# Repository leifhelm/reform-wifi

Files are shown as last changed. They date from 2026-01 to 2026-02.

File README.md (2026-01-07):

# WiFi Adapter for MNT Reform

This module is **untested**.

This adapter uses the PCIe and USB interfaces of the RCORE module, like the Pocket Reform.

The schematic is largely from [pocket-reform-wifi](https://source.mnt.re/reform/pocket-reform/-/tree/2fd691b93a8a8b05e923d17600f8ea777f0ab824/pocket-reform-wifi).

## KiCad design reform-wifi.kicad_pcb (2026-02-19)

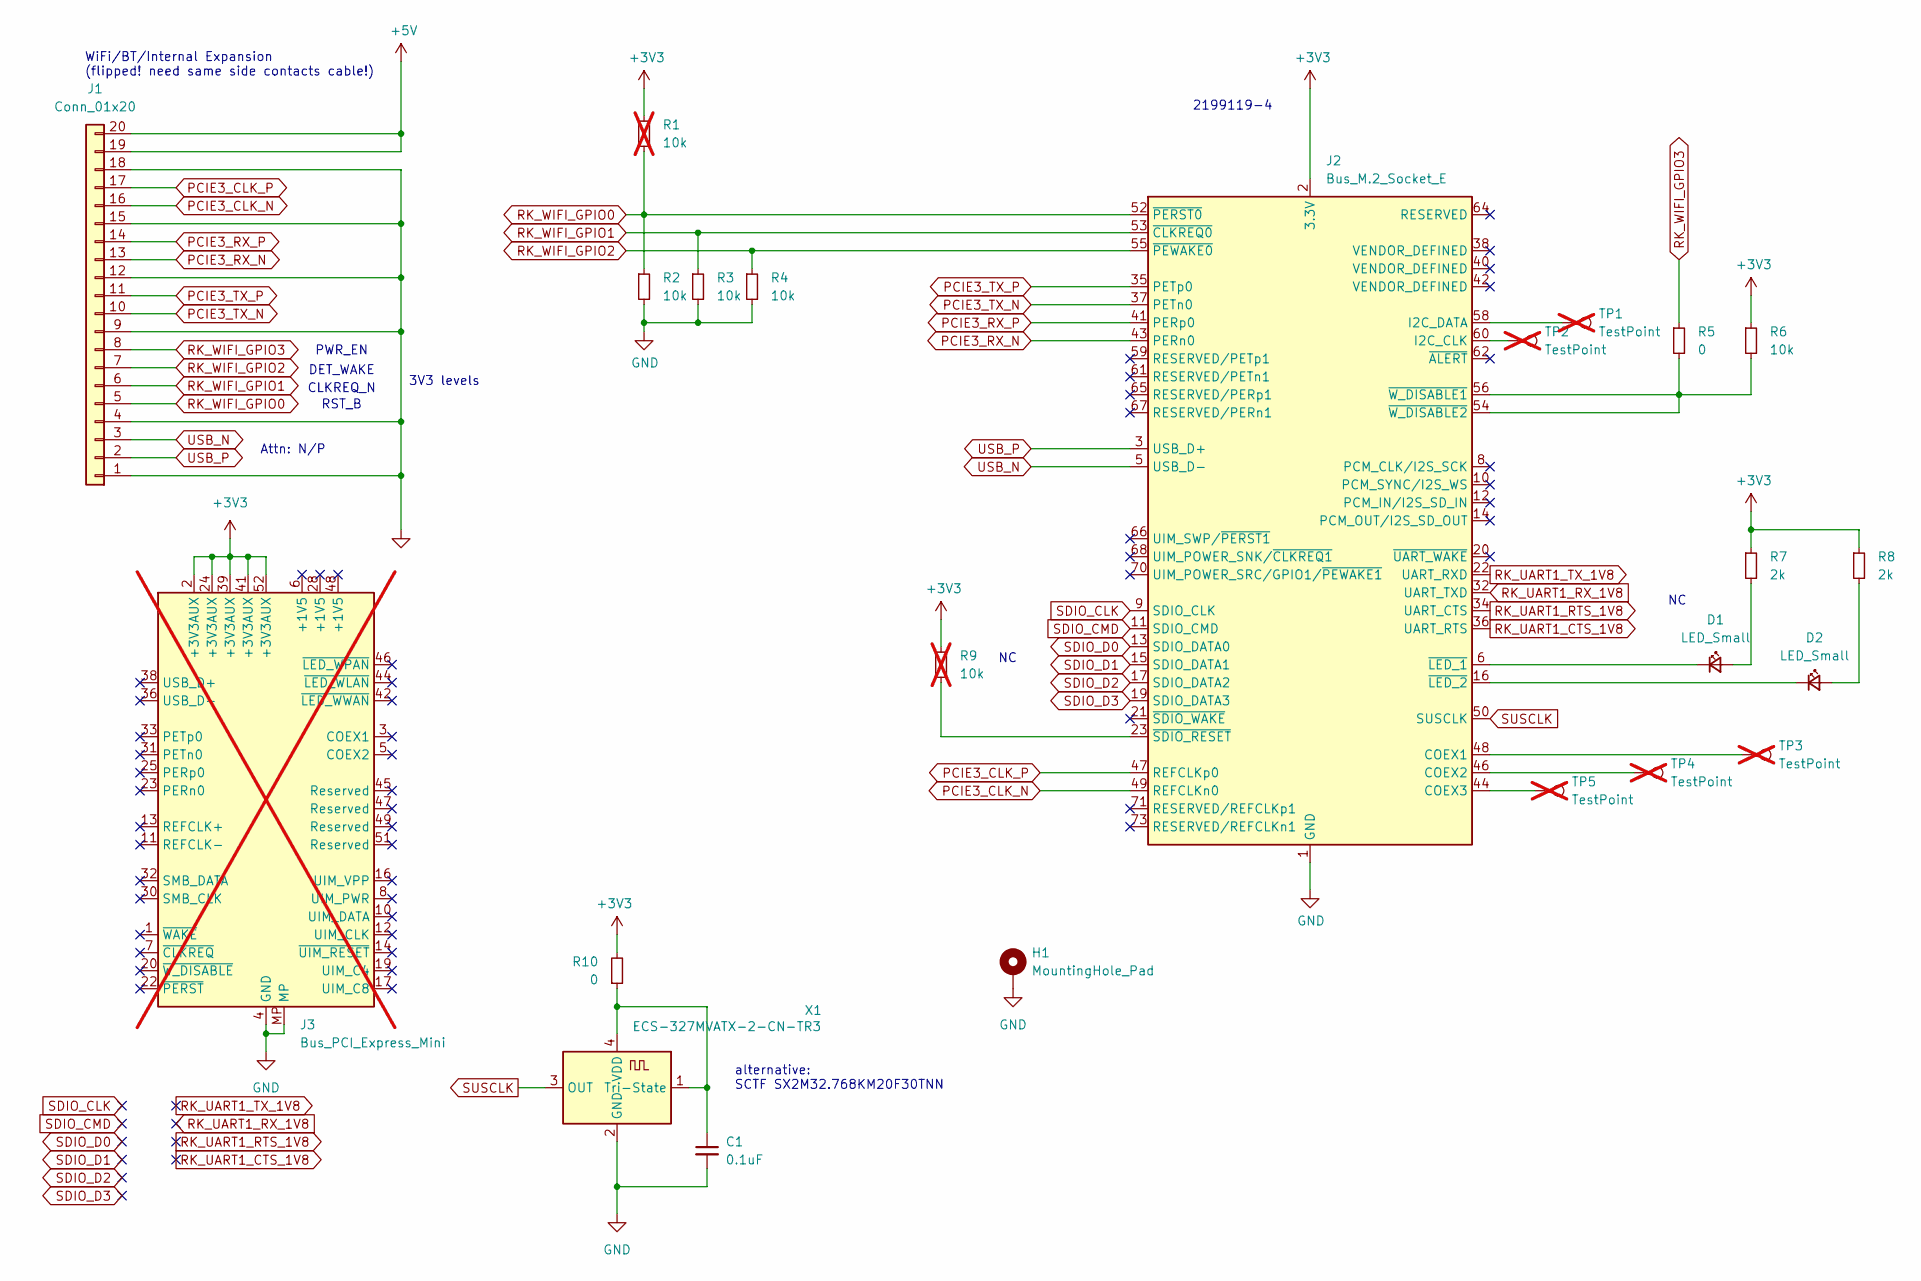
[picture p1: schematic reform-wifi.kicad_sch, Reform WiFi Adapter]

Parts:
C1: 0.1uF; C_0603_1608Metric; LCSC C77058
D1, D2: LED_Small; LED_0603_1608Metric; LCSC C5875723
H1: MountingHole_Pad; M.2 Mounting; LCSC C2916320
J1: Conn_01x20; Hirose_FH12-20S-0.5SH_1x20-1MP_P0.50mm_Horizontal; LCSC C596730
J2: Bus_M.2_Socket_E; TE_2199119-4; LCSC C5163551
J3: Bus_PCI_Express_Mini; BUS_PCI_Express_Mini_Full_Card; not fitted
R1, R9: 10k; R_0603_1608Metric; LCSC C98220; not fitted
R2, R3, R4, R6: 10k; R_0603_1608Metric; LCSC C98220
R5, R10: 0; R_0603_1608Metric; LCSC C95177
R7, R8: 2k; R_0603_1608Metric; LCSC C105576
TP1, TP2, TP3, TP4, TP5: TestPoint; TestPoint_Pad_D1.0mm; not fitted
X1: ECS-327MVATX-2-CN-TR3; Oscillator_SMD_ECS_2520MV-xxx-xx-4Pin_2.5x2.0mm; LCSC C2901603

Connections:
+3V3: J2.2 (3.3V), J2.4 (3.3V), J2.72 (3.3V), J2.74 (3.3V), J3.2 (+3V3AUX), J3.24 (+3V3AUX), J3.39 (+3V3AUX), J3.41 (+3V3AUX), J3.52 (+3V3AUX), R1.1, R6.1, R7.1, R8.1, R9.1, R10.2
+5V: J1.19, J1.20
GND: C1.2, H1.1, J1.1, J1.4, J1.9, J1.12, J1.15, J1.18, J2.1 (GND), J2.7 (GND), J2.18 (GND), J2.33 (GND), J2.39 (GND), J2.45 (GND), J2.51 (GND), J2.57 (GND), J2.63 (GND), J2.69 (GND), J2.75 (GND), J3.4 (GND), J3.9 (GND), J3.15 (GND), J3.18 (GND), J3.21 (GND), J3.26 (GND), J3.27 (GND), J3.29 (GND), J3.34 (GND), J3.35 (GND), J3.37 (GND), J3.40 (GND), J3.43 (GND), J3.50 (GND), J3.MP, R2.2, R3.2, R4.2, X1.2 (GND)
unnamed: D1.2 (A), R7.2
unnamed: D1.1 (K), J2.6 (~LED_1)
unnamed: D2.2 (A), R8.2
unnamed: D2.1 (K), J2.16 (~LED_2)
unnamed: J2.48 (COEX1), TP3.1
unnamed: J2.46 (COEX2), TP4.1
unnamed: J2.44 (COEX3), TP5.1
unnamed: J2.60 (I2C_CLK), TP2.1
unnamed: J2.58 (I2C_DATA), TP1.1
unnamed: J2.23 (~SDIO_RESET), R9.2
unnamed: J2.54 (~W_DISABLE2), J2.56 (~W_DISABLE1), R5.2, R6.2
unnamed: C1.1, R10.1, X1.1 (Tri-State), X1.4 (VDD)
PCIE3_CLK_N: J1.16, J2.49 (REFCLKn0)
PCIE3_CLK_P: J1.17, J2.47 (REFCLKp0)
PCIE3_RX_N: J1.13, J2.43 (PERn0)
PCIE3_RX_P: J1.14, J2.41 (PERp0)
PCIE3_TX_N: J1.10, J2.37 (PETn0)
PCIE3_TX_P: J1.11, J2.35 (PETp0)
RK_UART1_CTS_1V8: J2.36 (UART_RTS)
RK_UART1_RTS_1V8: J2.34 (UART_CTS)
RK_UART1_RX_1V8: J2.32 (UART_TXD)
RK_UART1_TX_1V8: J2.22 (UART_RXD)
RK_WIFI_GPIO0: J1.5, J2.52 (~PERST0), R1.2, R2.1
RK_WIFI_GPIO1: J1.6, J2.53 (~CLKREQ0), R3.1
RK_WIFI_GPIO2: J1.7, J2.55 (~PEWAKE0), R4.1
RK_WIFI_GPIO3: J1.8, R5.1
SDIO_CLK: J2.9 (SDIO_CLK)
SDIO_CMD: J2.11 (SDIO_CMD)
SDIO_D0: J2.13 (SDIO_DATA0)
SDIO_D1: J2.15 (SDIO_DATA1)
SDIO_D2: J2.17 (SDIO_DATA2)
SDIO_D3: J2.19 (SDIO_DATA3)
SUSCLK: J2.50 (SUSCLK), X1.3 (OUT)
USB_N: J1.3, J2.5 (USB_D-)
USB_P: J1.2, J2.3 (USB_D+)

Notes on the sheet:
3V3 levels
RST_B
PWR_EN
2199119-4
alternative: SCTF SX2M32.768KM20F30TNN
WiFi/BT/Internal Expansion (flipped! need same side contacts cable!)
DET_WAKE
CLKREQ_N
Attn: N/P

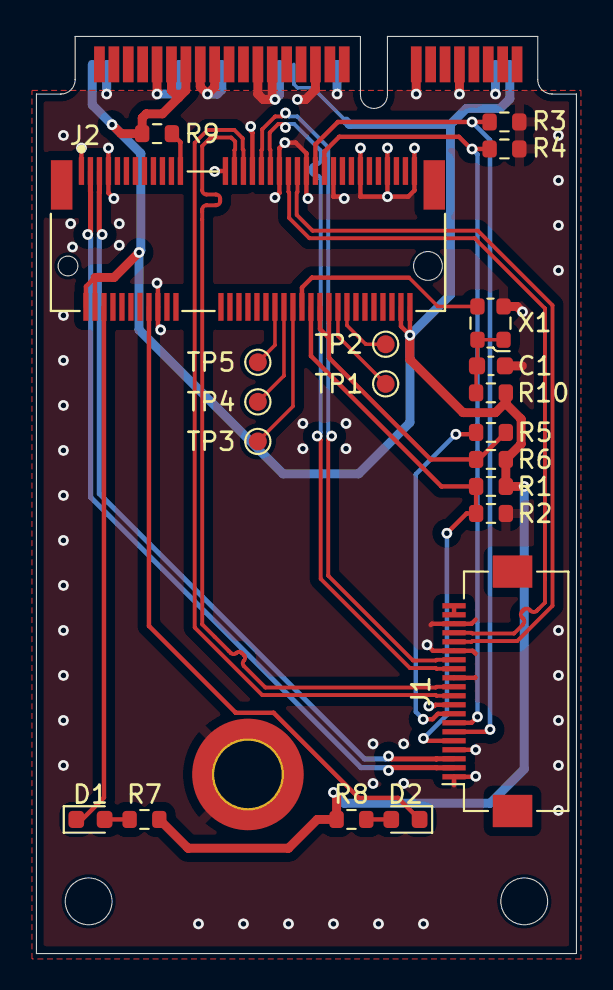
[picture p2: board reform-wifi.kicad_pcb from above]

Board: 4 copper layers, 30.0 x 51.0 mm, 23 parts (0 on the bottom side), 28 nets.
